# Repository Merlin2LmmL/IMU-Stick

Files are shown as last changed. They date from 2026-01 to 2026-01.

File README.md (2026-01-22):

# IMU-Stick
# Hardware
## Use Cases
When thinking abiout a new Project I remembered my Studica Robot, that i assembled and wrote software for. I was currently on the way of developing SLAM for the Robot using a LiDAR Sensor to allow for automomos sloving of tasks in the Robo Cup. I remembered, that pseudo IMU data can be generated using the cmd_vel ROS2 topic but those are often very unreliable due to drifting. That lead to the idea of buying a IMU Sensor. But what's better than buying someting? Correct! Building it yourself! So I began to think about what form factor I wanted the sensor to be. I figured that there is no real benefit of thinking about where to place the Sensor, since the motion is everywhere the same inside the robot so i chose the smallest possible form factor: Plugging the Sensor right into the Raspberry Pi 5, thats powering the Robot.

## Components
### Chip
For a chip I chose the all mighty rp2040 since its very easy to use and very popular. I obviously couldn't use an entire microcontroller like the rp zero or the XIOA rp2040, because they all already have a USB Port, which is useless for me and there is no microcontroller with a USB A Plug.

### USB Interface
Since the Sensor is going to be plugged into a Raspberry Pi 5, the only real option is USB A, because all the IO ports are occupied by the HAT that powers the Motorcontroller. USB A would also allow for universal use with basically any device. I concluded to USB 2.0 since 3. would be ovekill and only elevate the price of the PCB.

### IMU Senor
I decided to use the ICM-45686 in Single Interface Mode (SPI Interface to Host) since it is fits here really well and allows me to easily communicate with the Sensor over SPI and make programming the firmware later easier.

### Flash Memory
Since we're using a bare chip here, we obviously need flash memory to store the firmware onto it. There is not really much to say on why i settled for the W25Q128JVS because there are no real differences in Flash Memories.

## Pictures
### Schematic: 


### PCB


### Case


Also Note, that I purposely added a clutch powered way to open and close the Case. I plan on maybe gluing the top and bottom part of the case together, if they end up not having enough clutching power, because there is no real need in opening the case.


# Software
## Firmware
I wrote some Firmware for the Stick to send the motion data to the device its plugged in. Acess the firmware here: "firmware/imu_usb.c"

## Software use
Now to read the Sensor data, there are mltiple options. One is to immediately recieve the data via the terminal by executing this bash command:
```bash
screen /dev/ttyACM0 115200
```
or
```bash
cat /dev/ttyACM0
```
Another way would be to use a simple python script to read out the data like so:
```python
import serial

ser = serial.Serial('/dev/ttyACM0', 115200)

while True:
    line = ser.readline().decode().strip()
    ax, ay, az, gx, gy, gz = map(int, line.split(','))
    print(ax, ay, az, gx, gy, gz)
```
And using that same principle you can also publish the data onto a ROS2 topich, which is the way that I'm going to use it.

# BOM.csv
| Name | Total Cost | Quantity |
|---|---|---|
| PCB + Assembly + Parts | $81.84 | 5 |
| ICM45686 | $5.91 | 1 |

Total Price: 87.75$

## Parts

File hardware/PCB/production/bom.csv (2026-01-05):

Designator | Footprint | Quantity | Value | LCSC Part #
C10, C9 | 0603 | 2 | 10uF
C11, C13, C14, C15, C16, C17, C18, C19, C20, C21, C22 | 0603 | 11 | 0.1uF
C12, C23 | 0603 | 2 | 1uF
C2, C3 | 0603 | 2 | 100nF
C7, C8 | 0603 | 2 | 15pF
J1 | USB_A_CNCTech_1001-011-01101_Horizontal | 1 | USB_A
R11, R12 | 0603 | 2 | 1kR
R13 | 0603 | 1 | 10KR
R19, R9 | 0603 | 2 | 27R
SW1 | SW_Push_SPST_NO_Alps_SKRK | 1 | SW_Push
U1 | QFN-56-1EP_7x7mm_P0.4mm_EP3.2x3.2mm | 1 | RP2040
U2 | LGA-14_L3.0-W2.5-P0.50-TL | 1 | ICM-45686 | C22459454
U6 | SOT-223-3_TabPin2 | 1 | NCP1117-3.3_SOT223
U7 | SOIC-8_5.3x5.3mm_P1.27mm | 1 | W25Q128JVS
Y1 | Crystal_SMD_SeikoEpson_TSX3225-4Pin_3.2x2.5mm | 1 | 12 MHz

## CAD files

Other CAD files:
hardware/PCB/IMU Stick.f3z

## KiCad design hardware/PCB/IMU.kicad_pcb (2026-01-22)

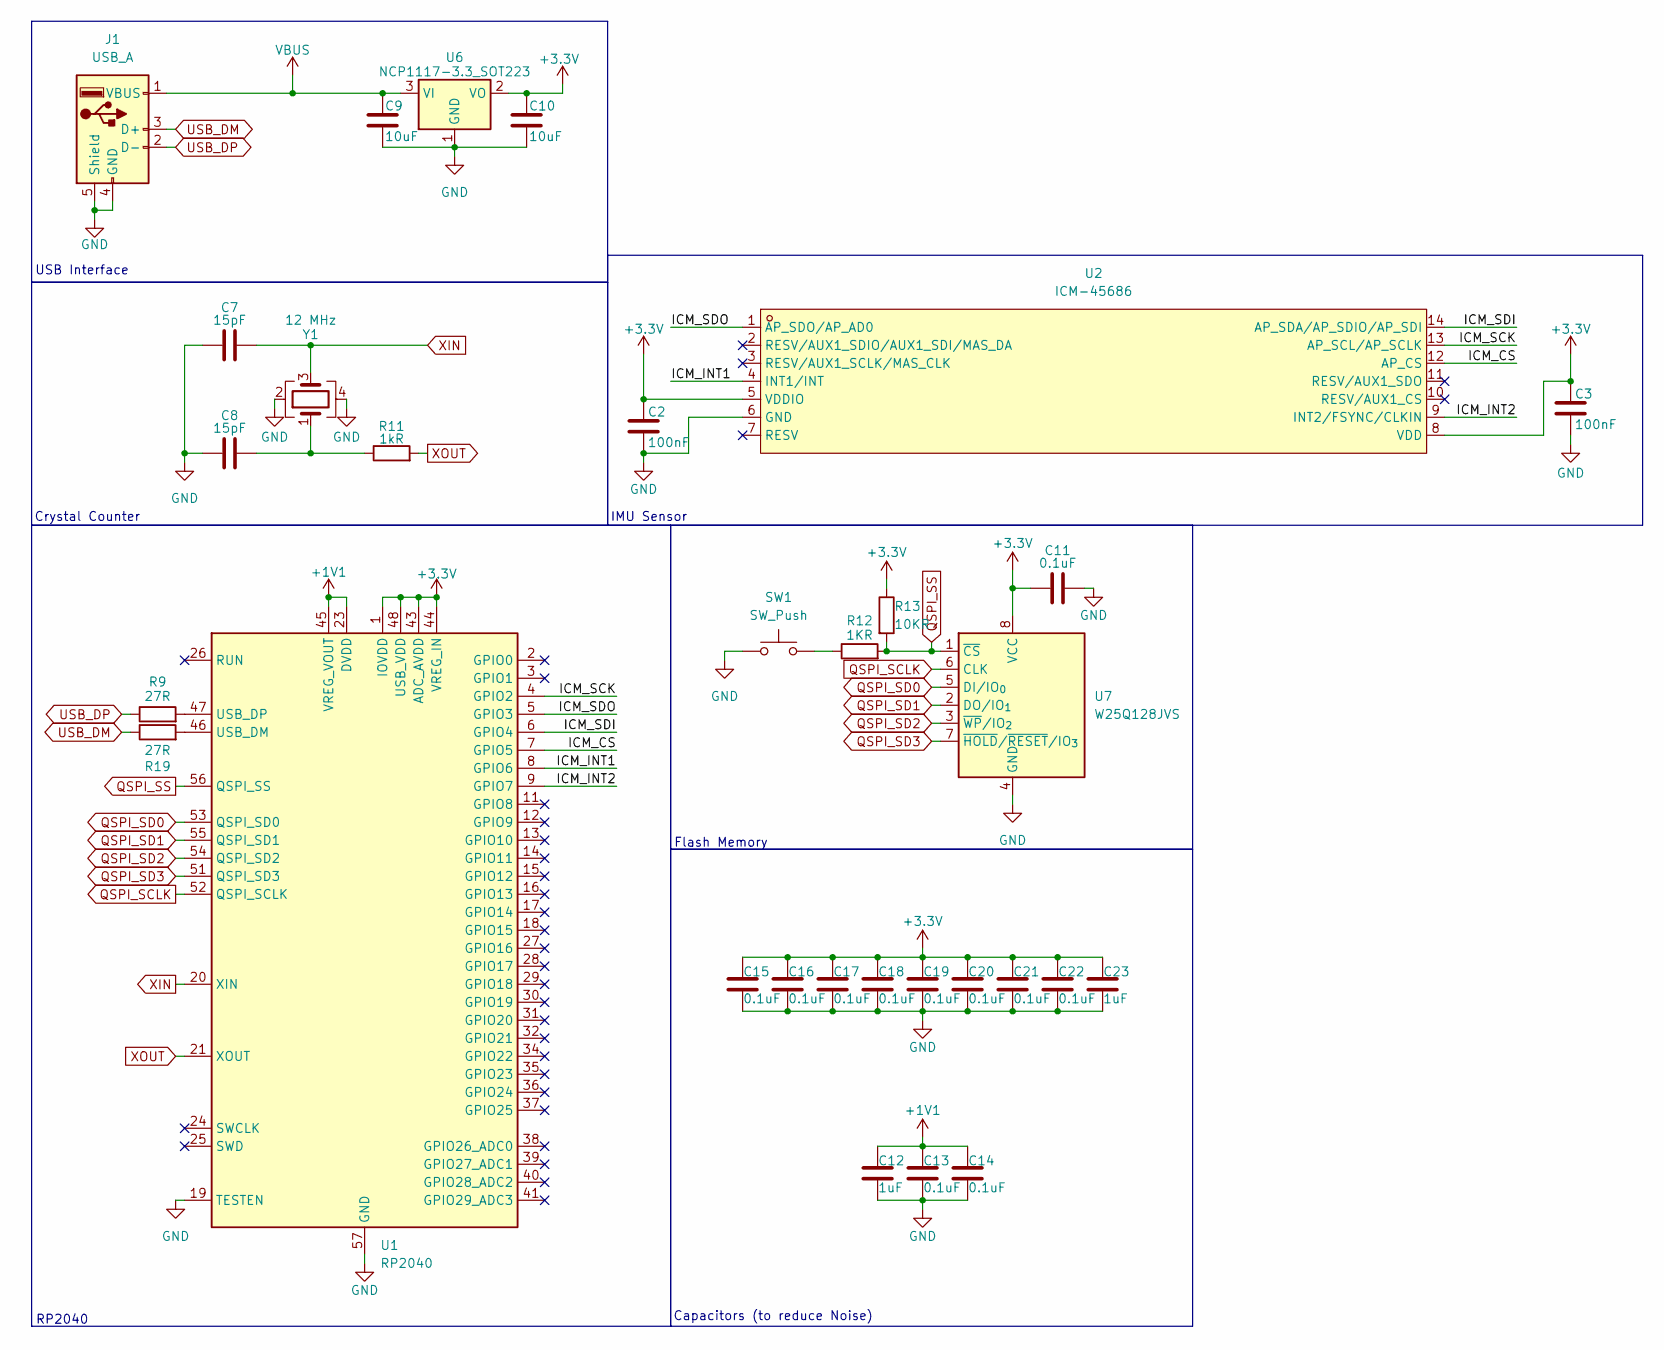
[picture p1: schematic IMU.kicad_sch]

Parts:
C2, C3: 100nF; C_0603_1608Metric_Pad1.08x0.95mm_HandSolder
C7, C8: 15pF; C_0603_1608Metric_Pad1.08x0.95mm_HandSolder
C9, C10: 10uF; C_0603_1608Metric_Pad1.08x0.95mm_HandSolder
C11, C13, C14, C15, C16, C17, C18, C19, C20, C21, C22: 0.1uF; C_0603_1608Metric_Pad1.08x0.95mm_HandSolder
C12, C23: 1uF; C_0603_1608Metric_Pad1.08x0.95mm_HandSolder
J1: USB_A; USB_A_CNCTech_1001-011-01101_Horizontal
R9, R19: 27R; R_0603_1608Metric_Pad0.98x0.95mm_HandSolder
R11: 1kR; R_0603_1608Metric_Pad0.98x0.95mm_HandSolder
R12: 1KR; R_0603_1608Metric_Pad0.98x0.95mm_HandSolder
R13: 10KR; R_0603_1608Metric_Pad0.98x0.95mm_HandSolder
SW1: SW_Push; SW_Push_SPST_NO_Alps_SKRK
U1: RP2040; QFN-56-1EP_7x7mm_P0.4mm_EP3.2x3.2mm
U2: ICM-45686; LGA-14_L3.0-W2.5-P0.50-TL; LCSC Part C22459454
U6: NCP1117-3.3_SOT223; SOT-223-3_TabPin2
U7: W25Q128JVS; SOIC-8_5.3x5.3mm_P1.27mm
Y1: 12 MHz; Crystal_SMD_SeikoEpson_TSX3225-4Pin_3.2x2.5mm

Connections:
+1V1: C12.1, C13.1, C14.1, U1.23 (DVDD), U1.45 (VREG_VOUT), U1.50 (DVDD)
+3.3V: C2.1, C3.1, C10.1, C11.1, C15.1, C16.1, C17.1, C18.1, C19.1, C20.1, C21.1, C22.1, C23.1, R13.1, U1.1 (IOVDD), U1.10 (IOVDD), U1.22 (IOVDD), U1.33 (IOVDD), U1.42 (IOVDD), U1.43 (ADC_AVDD), U1.44 (VREG_IN), U1.48 (USB_VDD), U1.49 (IOVDD), U2.5 (VDDIO), U2.8 (VDD), U6.2 (VO), U7.8 (VCC)
/ICM_CS: U1.7 (GPIO5), U2.12 (AP_CS)
/ICM_INT1: U1.8 (GPIO6), U2.4 (INT1/INT)
/ICM_INT2: U1.9 (GPIO7), U2.9 (INT2/FSYNC/CLKIN)
/ICM_SCK: U1.4 (GPIO2), U2.13 (AP_SCL/AP_SCLK)
/ICM_SDI: U1.6 (GPIO4), U2.14 (AP_SDA/AP_SDIO/AP_SDI)
/ICM_SDO: U1.5 (GPIO3), U2.1 (AP_SDO/AP_AD0)
GND: C2.2, C3.2, C7.1, C8.1, C9.2, C10.2, C11.2, C12.2, C13.2, C14.2, C15.2, C16.2, C17.2, C18.2, C19.2, C20.2, C21.2, C22.2, C23.2, J1.4 (GND), J1.5 (Shield), SW1.1, U1.19 (TESTEN), U1.57 (GND), U2.6 (GND), U6.1 (GND), U7.4 (GND), Y1.2, Y1.4
unnamed: C8.2, R11.1, Y1.1
unnamed: R12.1, SW1.2
unnamed: R19.2, U1.46 (USB_DM)
unnamed: R9.2, U1.47 (USB_DP)
QSPI_SCLK: U1.52 (QSPI_SCLK), U7.6 (CLK)
QSPI_SD0: U1.53 (QSPI_SD0), U7.5 (DI/IO_{0})
QSPI_SD1: U1.55 (QSPI_SD1), U7.2 (DO/IO_{1})
QSPI_SD2: U1.54 (QSPI_SD2), U7.3 (~WP/IO_{2})
QSPI_SD3: U1.51 (QSPI_SD3), U7.7 (~HOLD/~RESET/IO_{3})
QSPI_SS: R12.2, R13.2, U1.56 (QSPI_SS), U7.1 (~CS)
USB_DM: J1.3 (D+), R19.1
USB_DP: J1.2 (D-), R9.1
VBUS: C9.1, J1.1 (VBUS), U6.3 (VI)
XIN: C7.2, U1.20 (XIN), Y1.3
XOUT: R11.2, U1.21 (XOUT)

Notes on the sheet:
Flash Memory
Crystal Counter
IMU Sensor
USB Interface
RP2040
Capacitors (to reduce Noise)

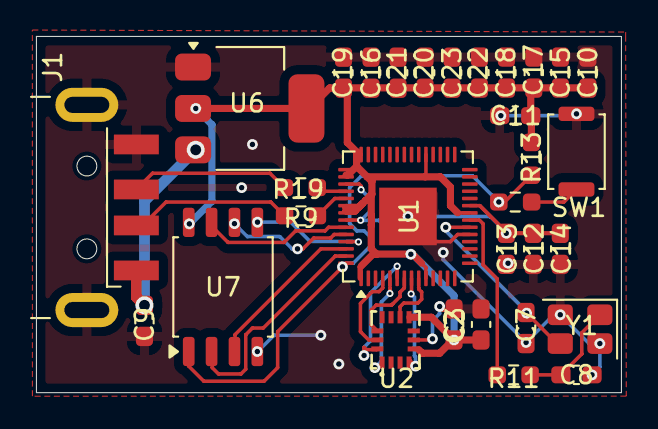
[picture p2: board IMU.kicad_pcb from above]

Board: 2 copper layers, 32.5 x 19.8 mm, 31 parts (0 on the bottom side), 24 nets.

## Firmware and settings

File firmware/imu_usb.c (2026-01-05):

#include <stdio.h>
#include "pico/stdlib.h"
#include "hardware/spi.h"
#include "hardware/gpio.h"
#include "tusb.h"

/* =========================
   Pin definitions
   ========================= */
#define SPI_PORT spi0

#define PIN_SCK   2
#define PIN_MISO  3
#define PIN_MOSI  4
#define PIN_CS    5
#define PIN_INT1  6

/* =========================
   ICM-45686 registers
   ========================= */
#define REG_WHO_AM_I      0x75
#define REG_PWR_MGMT0    0x4E
#define REG_ACCEL_CONFIG 0x50
#define REG_GYRO_CONFIG  0x4F
#define REG_ACCEL_XOUT_H 0x1F

#define WHO_AM_I_EXPECTED 0xE9  // Verify with datasheet revision

/* =========================
   SPI helpers
   ========================= */
static inline void cs_select() {
    gpio_put(PIN_CS, 0);
}

static inline void cs_deselect() {
    gpio_put(PIN_CS, 1);
}

uint8_t icm_read(uint8_t reg) {
    uint8_t tx[2] = { reg | 0x80, 0x00 };
    uint8_t rx[2];

    cs_select();
    spi_write_read_blocking(SPI_PORT, tx, rx, 2);
    cs_deselect();

    return rx[1];
}

void icm_write(uint8_t reg, uint8_t val) {
    uint8_t tx[2] = { reg & 0x7F, val };

    cs_select();
    spi_write_blocking(SPI_PORT, tx, 2);
    cs_deselect();
}

/* =========================
   IMU init
   ========================= */
void icm_init() {
    sleep_ms(50);

    uint8_t who = icm_read(REG_WHO_AM_I);
    if (who != WHO_AM_I_EXPECTED) {
        printf("ICM WHO_AM_I mismatch: 0x%02X\n", who);
    }

    /* Enable accel + gyro (low noise mode) */
    icm_write(REG_PWR_MGMT0, 0x0F);

    /* ±4g accel, 1 kHz ODR */
    icm_write(REG_ACCEL_CONFIG, 0x04);

    /* ±500 dps gyro, 1 kHz ODR */
    icm_write(REG_GYRO_CONFIG, 0x04);
}

/* =========================
   Read accel + gyro
   ========================= */
void icm_read_motion(int16_t *ax, int16_t *ay, int16_t *az,
                     int16_t *gx, int16_t *gy, int16_t *gz) {

    uint8_t tx[13];
    uint8_t rx[13];

    tx[0] = REG_ACCEL_XOUT_H | 0x80;
    for (int i = 1; i < 13; i++) tx[i] = 0;

    cs_select();
    spi_write_read_blocking(SPI_PORT, tx, rx, 13);
    cs_deselect();

    *ax = (rx[1] << 8) | rx[2];
    *ay = (rx[3] << 8) | rx[4];
    *az = (rx[5] << 8) | rx[6];
    *gx = (rx[7] << 8) | rx[8];
    *gy = (rx[9] << 8) | rx[10];
    *gz = (rx[11] << 8) | rx[12];
}

/* =========================
   Main
   ========================= */
int main() {
    stdio_init_all();
    tusb_init();

    /* SPI init */
    spi_init(SPI_PORT, 1 * 1000 * 1000);
    spi_set_format(SPI_PORT, 8, SPI_CPOL_0, SPI_CPHA_0, SPI_MSB_FIRST);

    gpio_set_function(PIN_SCK, GPIO_FUNC_SPI);
    gpio_set_function(PIN_MISO, GPIO_FUNC_SPI);
    gpio_set_function(PIN_MOSI, GPIO_FUNC_SPI);

    gpio_init(PIN_CS);
    gpio_set_dir(PIN_CS, GPIO_OUT);
    gpio_put(PIN_CS, 1);

    icm_init();

    int16_t ax, ay, az, gx, gy, gz;

    while (true) {
        tud_task();

        if (tud_cdc_connected()) {
            icm_read_motion(&ax, &ay, &az, &gx, &gy, &gz);

            printf("%d,%d,%d,%d,%d,%d\n",
                   ax, ay, az, gx, gy, gz);
        }

        sleep_ms(5); // ~200 Hz
    }
}

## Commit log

2026-01-05 Added all kiCAD files
    [IMU.kicad_pcb, IMU.kicad_sch, bom.csv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]
2026-01-05 Enhance README with hardware and software details
    Expanded the README with detailed hardware and software sections, including use cases, components, firmware, and BOM.
2026-01-05 Revise BOM table and include total cost
    Updated BOM table format and added total cost.
2026-01-22 Reworked PCB
    Moved Decoupeling Capacitors physically closer to buck converter and RP2040.
    [IMU Stick.f3z, IMU.kicad_pcb, freerouting.dsn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]
2026-01-22 Updated Picture for PCB
